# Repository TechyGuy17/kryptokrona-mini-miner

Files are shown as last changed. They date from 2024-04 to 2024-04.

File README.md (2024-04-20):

** THE HARDWARE IS CURRENTLY NOT TESTED **

# Kryptokrona mini miner
A bare minimum miner with a Cortex-A53 Allwinner H616 SoC made with KiCad

<p align="center">
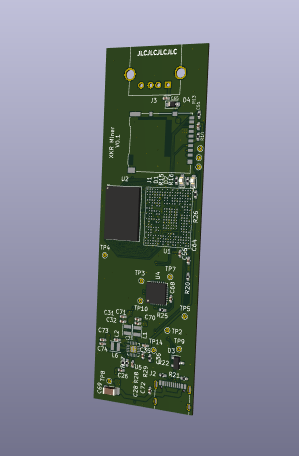
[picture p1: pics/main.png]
     
</p>

## Overview
A simple as possible SBC for mining kryptokrona (XKR), based on [Kononenko-K's h616 devboard](https://github.com/Kononenko-K/Allwinner_H616_Devboard/)

## [Hardware](Hardware)

The board features 64-bit 1.5GHz Quad-Core Cortex-A53 Allwinner H616 SOC, up to 8 Gbit (1 GB) of FBGA-96 16x DDR3 RAM, Micro SD slot, USB HS Host connector and integrated CP2102 USB-UART converter. 4 layers; 3,5/3,5 mil; 0,35/0,15 via, 80u prepreg.
There are [KiCad project](/Hardware), [Gerber files](/Hardware/gerber) and [PDF](/Hardware/output.pdf) avaliable.

## Software
** NOT TESTED SOFTWARE, IT COMPILES BUT MIGHT NOT ACTUALLY WORK ** 
Due to the switch to the more accessable AXP313a, the project is no longer fully compatible with the Orange Pi zero 2- But there is a workaround!

For this guide we will be using armbian, since its lightweight and has support for our processor.

The recommended OS to run this in is Ubuntu 22.04

start by downloading this repo to get the necessary files

```git clone https://github.com/TechyGuy17/kryptokrona-mini-miner```

After that we want to download the "Armbian Builder"

```git clone https://github.com/armbian/build && cd build```

Now we will do a dry run of the builder to let it download all the sources and also fix the file structure

```./compile.sh build BOARD=orangepizero2 BRANCH=current BUILD_DESKTOP=no BUILD_MINIMAL=yes KERNEL_CONFIGURE=no RELEASE=bookworm```

Now we are ready to start doing the patching. If you havent moved around the folders you can use theese commands to do the whole process

```mkdir userpatches/kernel/archive/sunxi-6.6```

```cp ../kryptokrona-mini-miner/Patches/updated-tp-axp313a.patch userpatches/kernel/archive/sunxi-6.6 ```

```cp ../kryptokrona-mini-miner/Patches/updated-tp-axp313a-uboot.patch userpatches/u-boot/u-boot-sunxi```

What this does is move in a few files that make it so we switch out everything regarding the AXP305 to 313a

Now we are ready to build for real!

```./compile.sh build BOARD=orangepizero2 BRANCH=current BUILD_DESKTOP=no BUILD_MINIMAL=yes KERNEL_CONFIGURE=no RELEASE=bookworm```

After this, you should have an image ready to be flashed to a SD card and then ready to be booted! Plug in an wifi/ethernet adapter in the board and a USB-c cable from your computer to the miner and then it should light up! The board will show up as a serial device and can be accessed through software like puTTY or minicom. settings are 115200,8,1 meaning 115200 baud rate, 8 bits and one stop bit.

# Bonus
If you want XKRig (XMRig) preinstalled to your keep on reading!

Run the following command to move the required script to the right folder 
```mv ../kryptokrona-mini-miner/Patches/customize-image.sh userpatches```

When this is in place, rerun the compile 

```./compile.sh build BOARD=orangepizero2 BRANCH=current BUILD_DESKTOP=no BUILD_MINIMAL=yes KERNEL_CONFIGURE=no RELEASE=bookworm```

This will go a lot faster since most the code is cached by now

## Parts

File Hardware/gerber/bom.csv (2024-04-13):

Designator | Footprint | Quantity | Value | LCSC Part #
C1, C2, C58, C61, C62 | 0402 | 5 | 100n
C10, C11, C12, C13, C14, C3, C4, C5, C57, C6, C72, C8, C9 | 0402 | 13 | 1u
C26, C27, C28, C29, C30, C31, C32, C33, C34, C35, C36, C51, C70, C71, C73, C74 | 0402 | 16 | 10u
C40, C41, C42, C43, C44, C45, C46, C47, C48, C49, C50, C52, C53, C56 | 0402 | 14 | 2.2u
C54, C55 | 0402 | 2 | 470n
C59, C60 | 0402 | 2 | 18p
C63 | 0402 | 1 | 220n
C64 | 0402 | 1 | 1n
C65, C68 | 0402 | 2 | 4.7u
C66, C67, C69 | 1206 | 3 | 47u
C7 | 0402 | 1 | 2.2p
D1, D2 | 0603 | 2 | LED
D3 | SOT-23 | 1 | SP0502BAHT
D4 | D_SOD-323_HandSoldering | 1 | D_Schottky
J1 | microSD_HC_Hirose_DM3AT-SF-PEJM5 | 1 | Micro_SD_Card_Det2
J2 | USB_C_Receptacle_Palconn_UTC16-G | 1 | USB_C_Receptacle_USB2.0
J3 | USB_A_Molex_67643_Horizontal | 1 | USB_A
L1, L2, L6 | L_Changjiang_FNR252010S | 3 | 1,5uH
R1, R15, R16, R17, R18, R2 | 0402 | 6 | 2k
R10 | 0402 | 1 | 1R
R11 | 0402 | 1 | 33R
R12, R13, R20, R25, R26 | 0402 | 5 | 10k
R14 | 0402 | 1 | 1k
R19 | 0402 | 1 | 150k
R21, R22 | 0402 | 2 | 5.1k
R27, R28 | 0402 | 2 | NC
R29 | 0402 | 1 | 0R
R3, R5, R6 | 0402 | 3 | 240R
R4 | 0402 | 1 | 100R
TP10, TP11, TP12, TP13, TP14, TP2, TP3, TP4, TP5, TP7, TP8, TP9 | TestPoint_THTPad_D1.0mm_Drill0.5mm | 12 | TestPoint
U1 | H616_TFBGA284 | 1 | H616
U2 | BGA-96_9.0x13.0mm_Layout2x3x16_P0.8mm | 1 | DDR3 FBGA-96
U4 | QFN-28-1EP_5x5mm_P0.5mm_EP3.35x3.35mm | 1 | CP2102N-Axx-xQFN28
U5 | QFN-20-1EP_3x3mm_P0.4mm_EP1.65x1.65mm_ThermalVias | 1 | ~
Y1 | Crystal_SMD_2520-4Pin_2.5x2.0mm | 1 | 25MHz

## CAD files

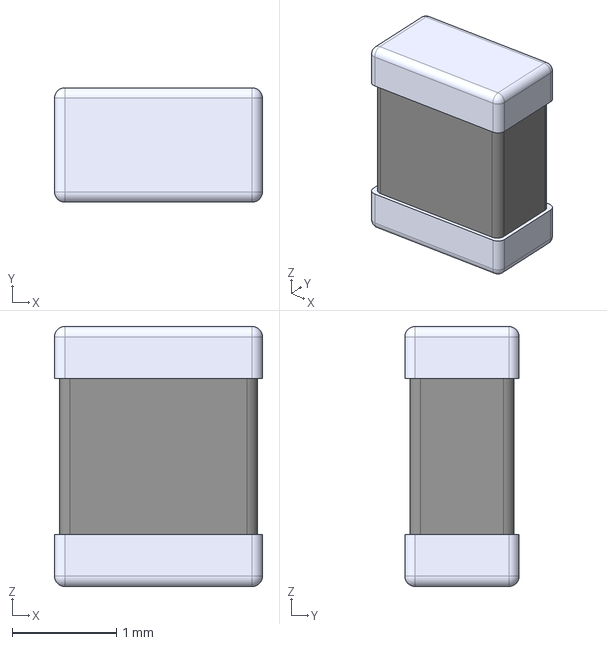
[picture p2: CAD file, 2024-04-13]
Hardware/Inductor_2520.step
2.00 x 1.10 x 2.50 mm

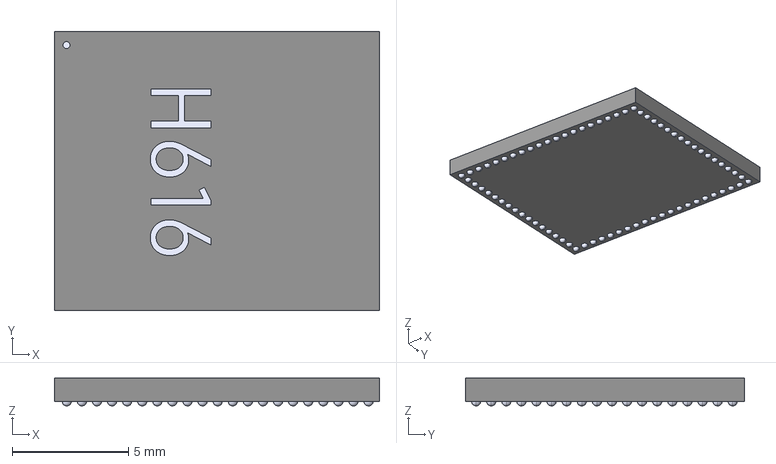
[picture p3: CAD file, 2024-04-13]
Hardware/SoC_H616.step
14.0 x 12.0 x 1.20 mm

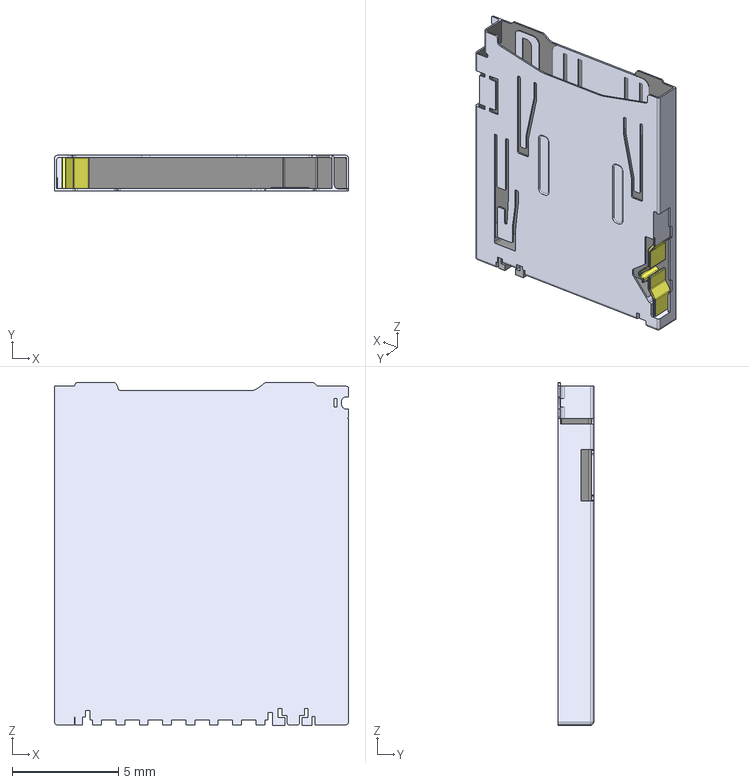
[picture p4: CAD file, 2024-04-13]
Hardware/MicroSD_DM3AT.step
13.8 x 1.68 x 16.2 mm

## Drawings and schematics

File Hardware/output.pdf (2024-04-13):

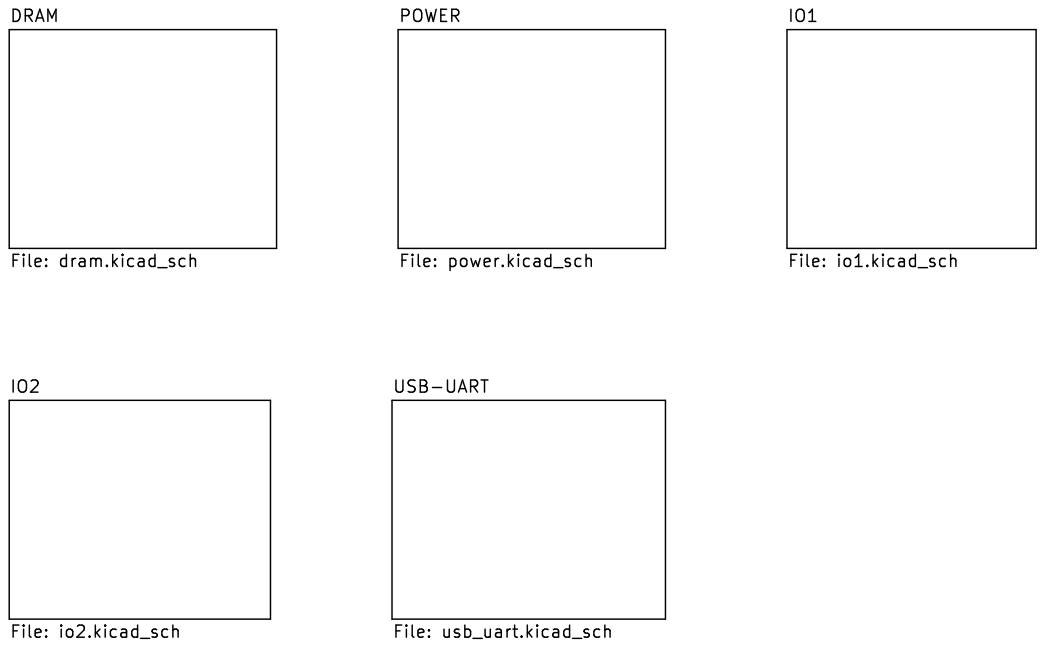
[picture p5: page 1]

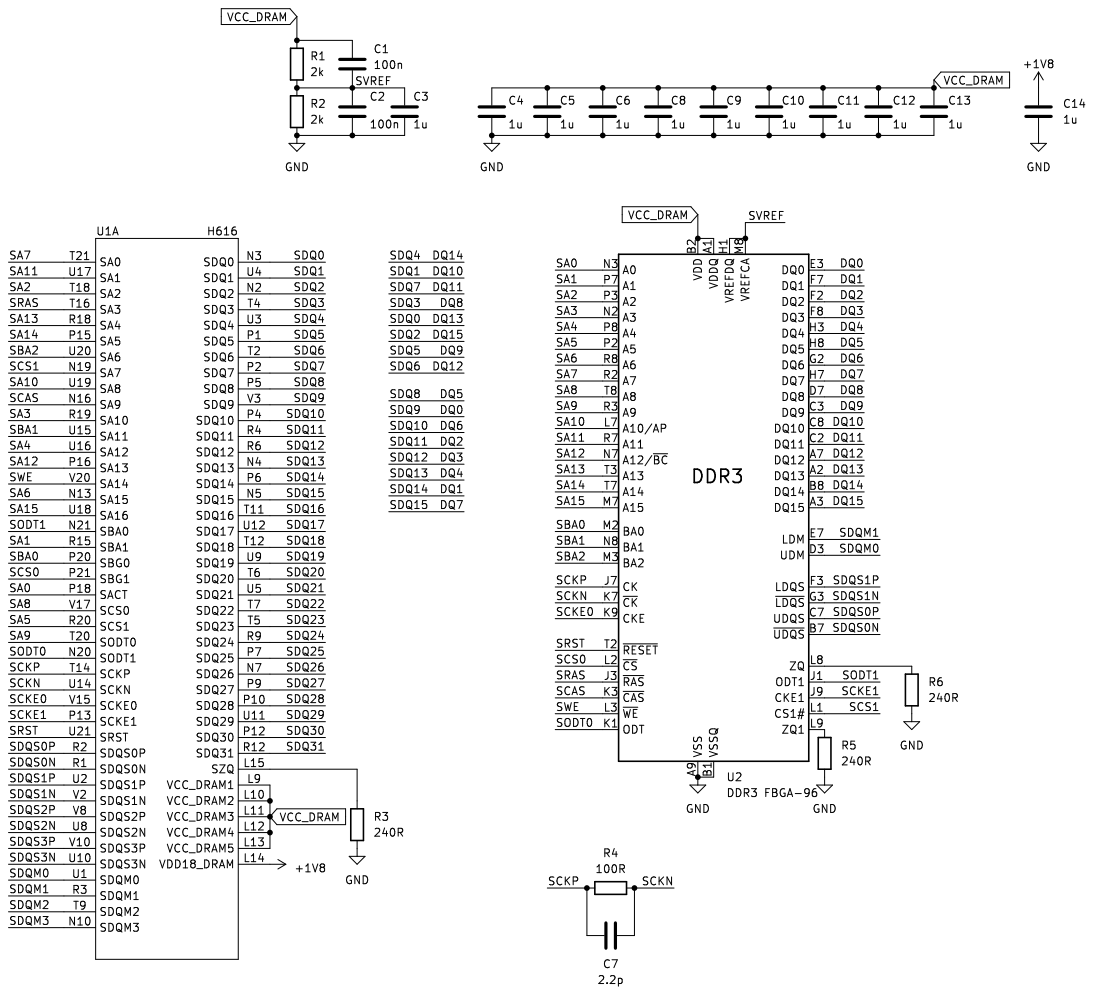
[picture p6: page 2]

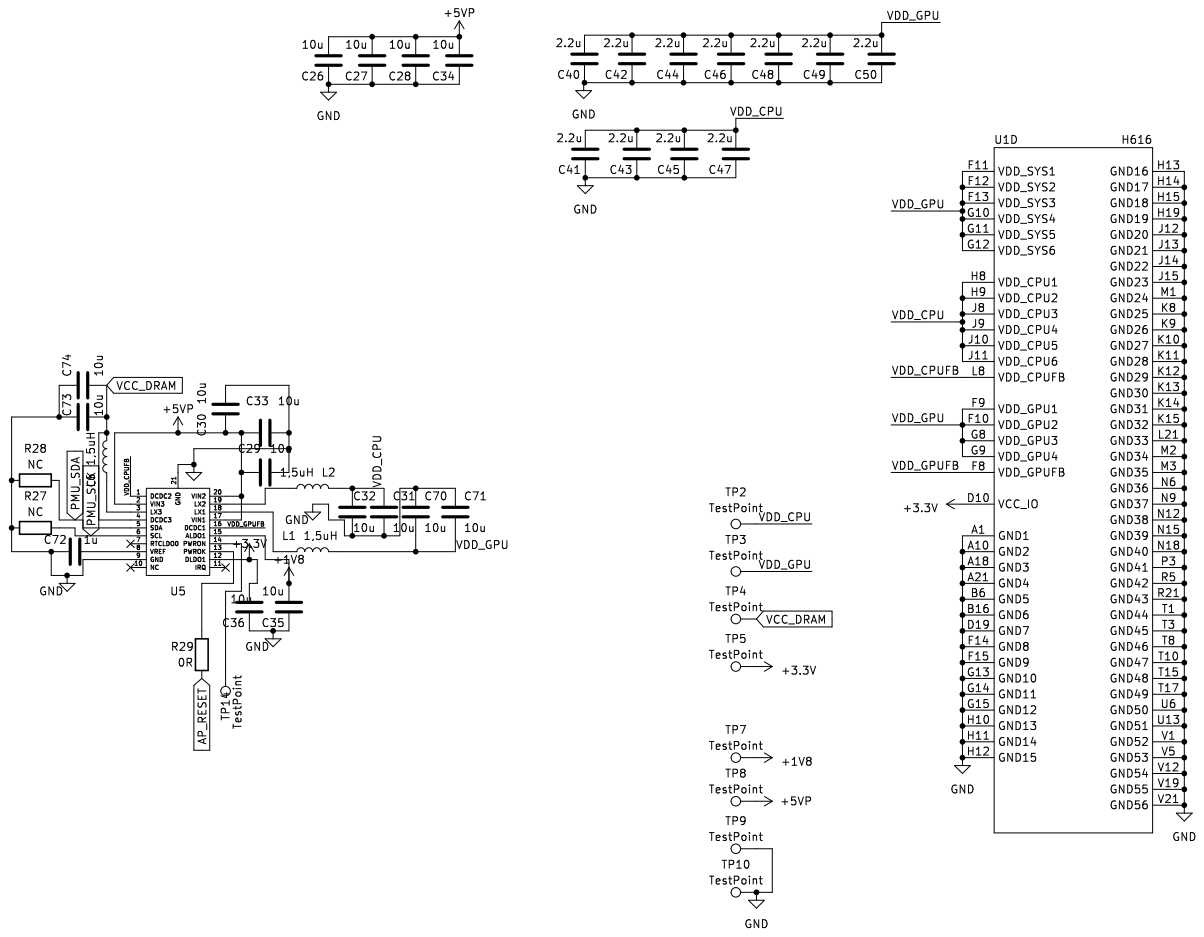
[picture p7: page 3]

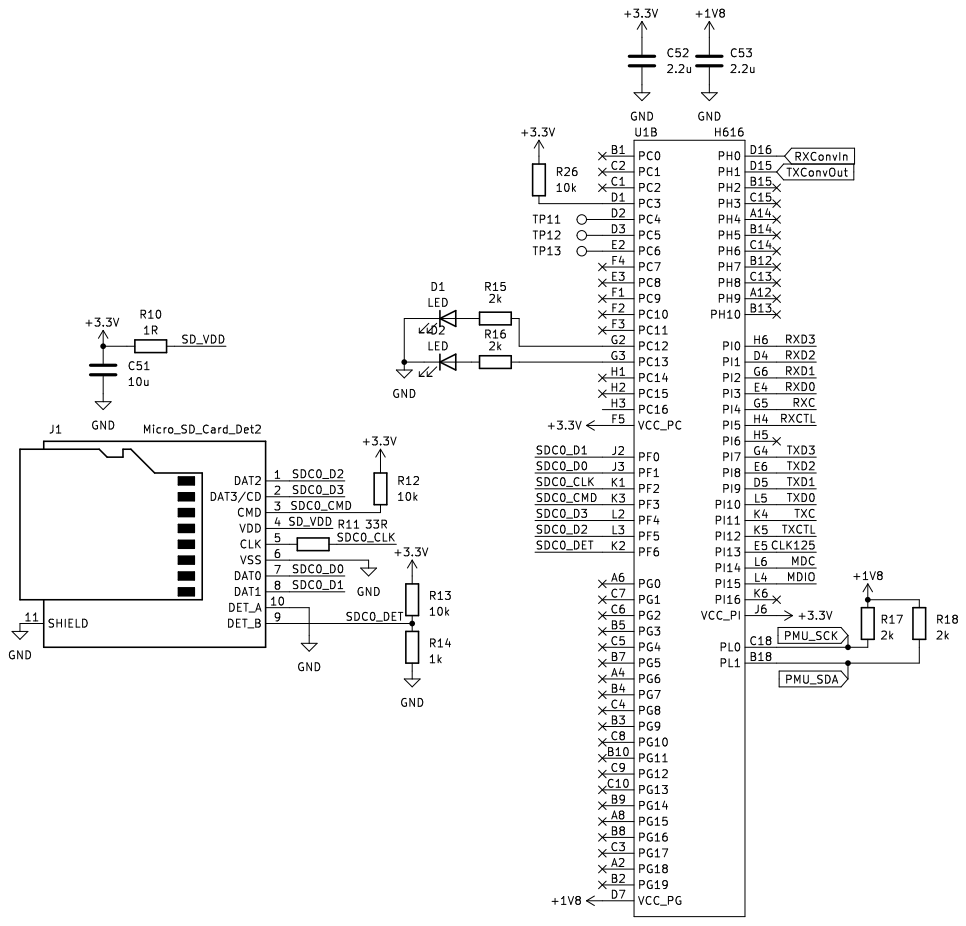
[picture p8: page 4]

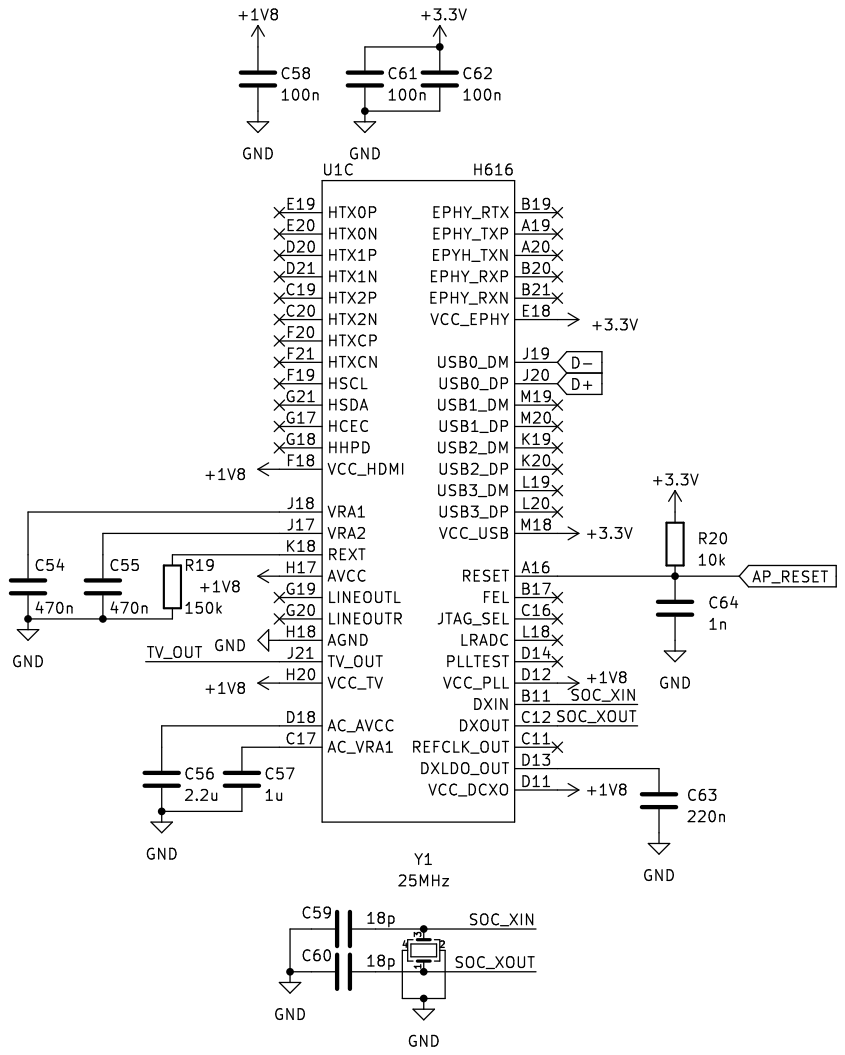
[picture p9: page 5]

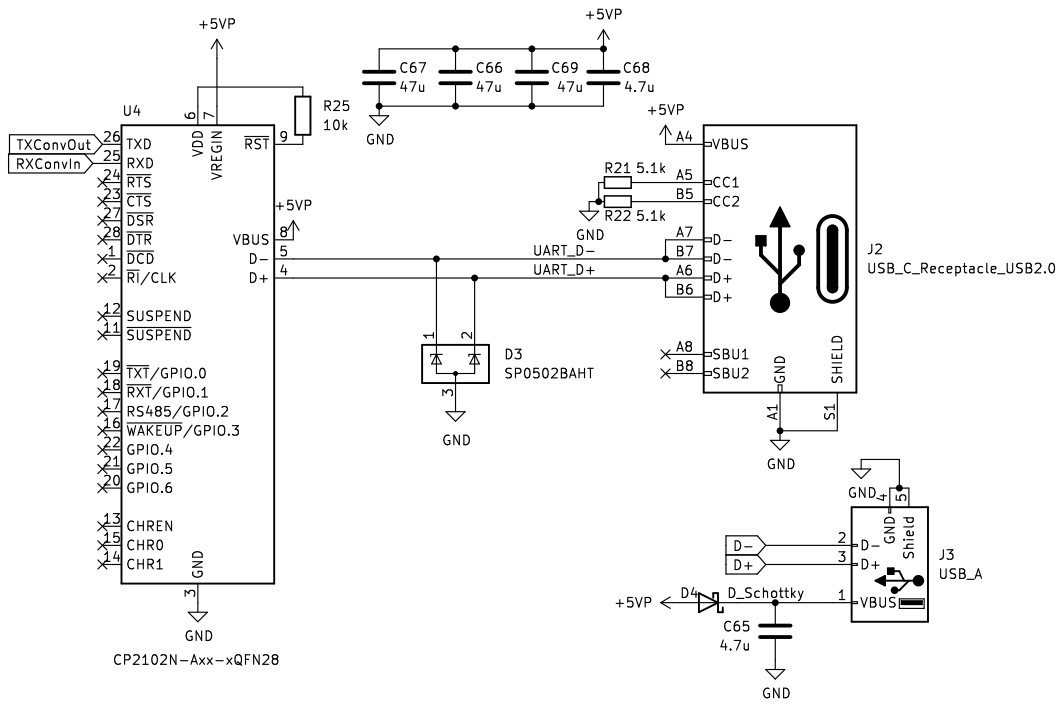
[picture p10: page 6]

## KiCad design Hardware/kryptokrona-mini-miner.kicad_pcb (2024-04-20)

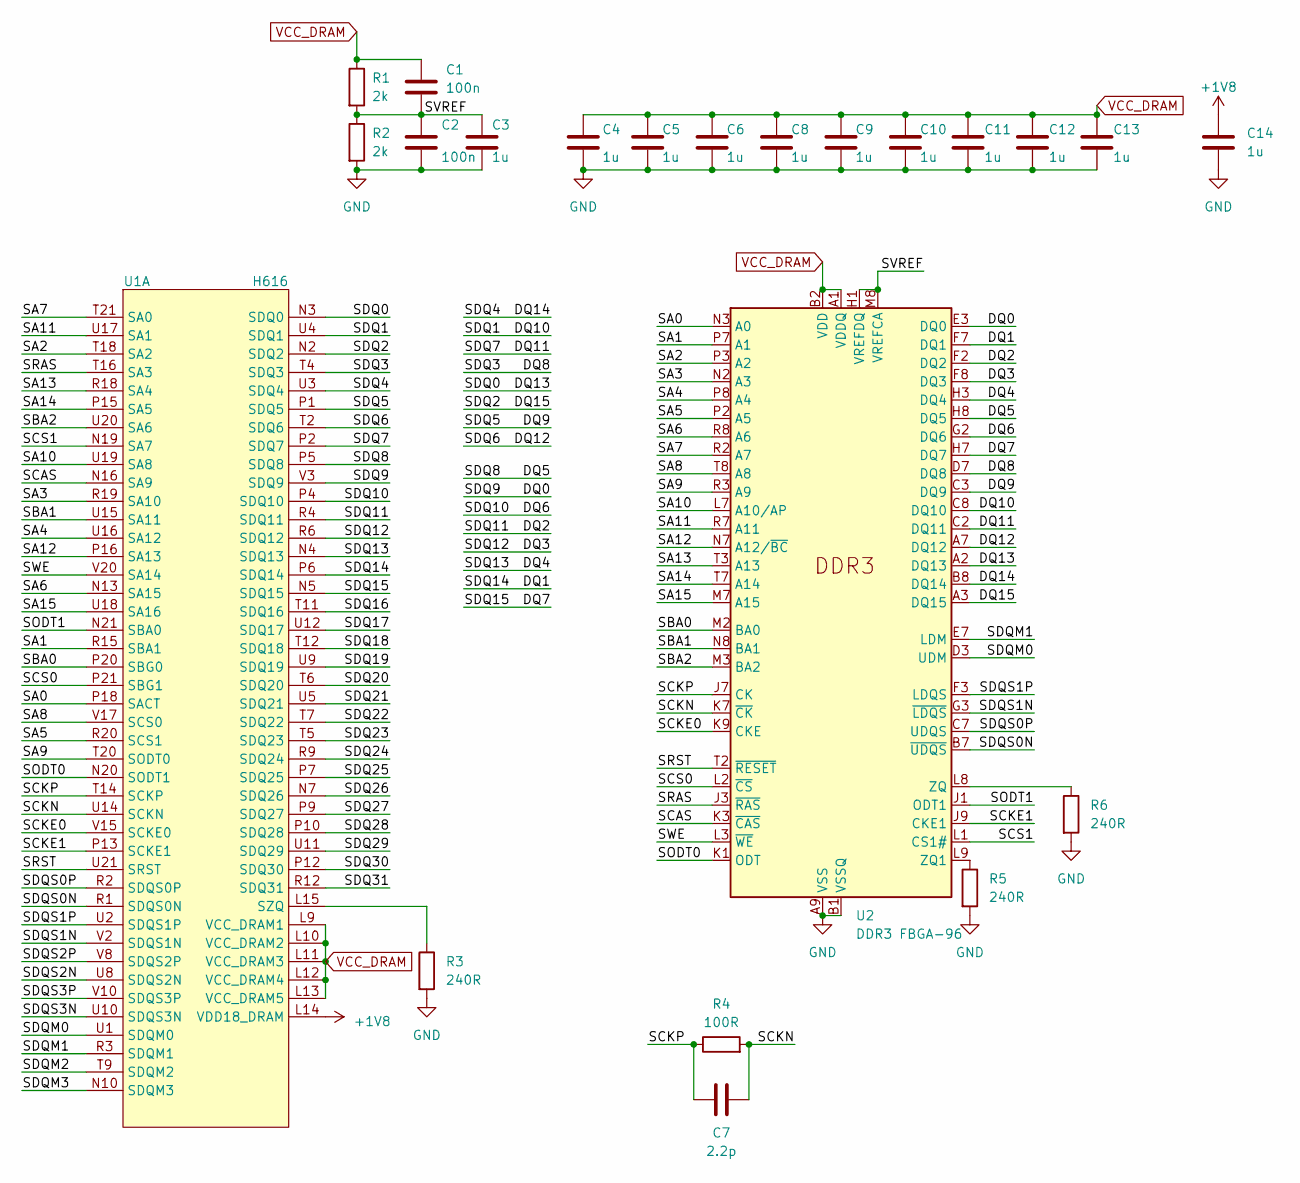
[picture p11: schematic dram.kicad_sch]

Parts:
C1, C2: 100n; C_0402_1005Metric_Pad0.74x0.62mm_HandSolder
C3, C4, C5, C6, C8, C9, C10, C11, C12, C13, C14: 1u; C_0402_1005Metric_Pad0.74x0.62mm_HandSolder
C7: 2.2p; C_0402_1005Metric_Pad0.74x0.62mm_HandSolder
R1, R2: 2k; R_0402_1005Metric_Pad0.72x0.64mm_HandSolder
R3, R5, R6: 240R; R_0402_1005Metric_Pad0.72x0.64mm_HandSolder
R4: 100R; R_0402_1005Metric_Pad0.72x0.64mm_HandSolder
U1: H616; H616_TFBGA284
U2: DDR3 FBGA-96; BGA-96_9.0x13.0mm_Layout2x3x16_P0.8mm

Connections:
+1V8: C14.1, U1.L14 (VDD18_DRAM); also elsewhere on the board
/DRAM/DQ0: U1.V3 (SDQ9), U2.E3 (DQ0)
/DRAM/DQ1: U1.P6 (SDQ14), U2.F7 (DQ1)
/DRAM/DQ2: U1.R4 (SDQ11), U2.F2 (DQ2)
/DRAM/DQ3: U1.R6 (SDQ12), U2.F8 (DQ3)
/DRAM/DQ4: U1.N4 (SDQ13), U2.H3 (DQ4)
/DRAM/DQ5: U1.P5 (SDQ8), U2.H8 (DQ5)
/DRAM/DQ6: U1.P4 (SDQ10), U2.G2 (DQ6)
/DRAM/DQ7: U1.N5 (SDQ15), U2.H7 (DQ7)
/DRAM/DQ8: U1.T4 (SDQ3), U2.D7 (DQ8)
/DRAM/DQ9: U1.P1 (SDQ5), U2.C3 (DQ9)
/DRAM/DQ10: U1.U4 (SDQ1), U2.C8 (DQ10)
/DRAM/DQ11: U1.P2 (SDQ7), U2.C2 (DQ11)
/DRAM/DQ12: U1.T2 (SDQ6), U2.A7 (DQ12)
/DRAM/DQ13: U1.N3 (SDQ0), U2.A2 (DQ13)
/DRAM/DQ14: U1.U3 (SDQ4), U2.B8 (DQ14)
/DRAM/DQ15: U1.N2 (SDQ2), U2.A3 (DQ15)
/DRAM/SA0: U1.P18 (SACT), U2.N3 (A0)
/DRAM/SA1: U1.R15 (SBA1), U2.P7 (A1)
/DRAM/SA2: U1.T18 (SA2), U2.P3 (A2)
/DRAM/SA3: U1.R19 (SA10), U2.N2 (A3)
/DRAM/SA4: U1.U16 (SA12), U2.P8 (A4)
/DRAM/SA5: U1.R20 (SCS1), U2.P2 (A5)
/DRAM/SA6: U1.N13 (SA15), U2.R8 (A6)
/DRAM/SA7: U1.T21 (SA0), U2.R2 (A7)
/DRAM/SA8: U1.V17 (SCS0), U2.T8 (A8)
/DRAM/SA9: U1.T20 (SODT0), U2.R3 (A9)
/DRAM/SA10: U1.U19 (SA8), U2.L7 (A10/AP)
/DRAM/SA11: U1.U17 (SA1), U2.R7 (A11)
/DRAM/SA12: U1.P16 (SA13), U2.N7 (A12/~BC)
/DRAM/SA13: U1.R18 (SA4), U2.T3 (A13)
/DRAM/SA14: U1.P15 (SA5), U2.T7 (A14)
/DRAM/SA15: U1.U18 (SA16), U2.M7 (A15)
/DRAM/SBA0: U1.P20 (SBG0), U2.M2 (BA0)
/DRAM/SBA1: U1.U15 (SA11), U2.N8 (BA1)
/DRAM/SBA2: U1.U20 (SA6), U2.M3 (BA2)
/DRAM/SCAS: U1.N16 (SA9), U2.K3 (~CAS)
/DRAM/SCKE0: U1.V15 (SCKE0), U2.K9 (CKE)
/DRAM/SCKE1: U1.P13 (SCKE1), U2.J9 (CKE1)
/DRAM/SCKN: C7.2, R4.2, U1.U14 (SCKN), U2.K7 (~CK)
/DRAM/SCKP: C7.1, R4.1, U1.T14 (SCKP), U2.J7 (CK)
/DRAM/SCS0: U1.P21 (SBG1), U2.L2 (~CS)
/DRAM/SCS1: U1.N19 (SA7), U2.L1 (CS1#)
/DRAM/SDQ16: U1.T11 (SDQ16)
/DRAM/SDQ17: U1.U12 (SDQ17)
/DRAM/SDQ18: U1.T12 (SDQ18)
/DRAM/SDQ19: U1.U9 (SDQ19)
/DRAM/SDQ20: U1.T6 (SDQ20)
/DRAM/SDQ21: U1.U5 (SDQ21)
/DRAM/SDQ22: U1.T7 (SDQ22)
/DRAM/SDQ23: U1.T5 (SDQ23)
/DRAM/SDQ24: U1.R9 (SDQ24)
/DRAM/SDQ25: U1.P7 (SDQ25)
/DRAM/SDQ26: U1.N7 (SDQ26)
/DRAM/SDQ27: U1.P9 (SDQ27)
/DRAM/SDQ28: U1.P10 (SDQ28)
/DRAM/SDQ29: U1.U11 (SDQ29)
/DRAM/SDQ30: U1.P12 (SDQ30)
/DRAM/SDQ31: U1.R12 (SDQ31)
/DRAM/SDQM0: U1.U1 (SDQM0), U2.D3 (UDM)
/DRAM/SDQM1: U1.R3 (SDQM1), U2.E7 (LDM)
/DRAM/SDQM2: U1.T9 (SDQM2)
/DRAM/SDQM3: U1.N10 (SDQM3)
/DRAM/SDQS0N: U1.R1 (SDQS0N), U2.B7 (~UDQS)
/DRAM/SDQS0P: U1.R2 (SDQS0P), U2.C7 (UDQS)
/DRAM/SDQS1N: U1.V2 (SDQS1N), U2.G3 (~LDQS)
/DRAM/SDQS1P: U1.U2 (SDQS1P), U2.F3 (LDQS)
/DRAM/SDQS2N: U1.U8 (SDQS2N)
/DRAM/SDQS2P: U1.V8 (SDQS2P)
/DRAM/SDQS3N: U1.U10 (SDQS3N)
/DRAM/SDQS3P: U1.V10 (SDQS3P)
/DRAM/SODT0: U1.N20 (SODT1), U2.K1 (ODT)
/DRAM/SODT1: U1.N21 (SBA0), U2.J1 (ODT1)
/DRAM/SRAS: U1.T16 (SA3), U2.J3 (~RAS)
/DRAM/SRST: U1.U21 (SRST), U2.T2 (~RESET)
/DRAM/SVREF: C1.2, C2.1, C3.1, R1.2, R2.1, U2.H1 (VREFDQ), U2.M8 (VREFCA)
/DRAM/SWE: U1.V20 (SA14), U2.L3 (~WE)
GND: C2.2, C3.2, C4.2, C5.2, C6.2, C8.2, C9.2, C10.2, C11.2, C12.2, C13.2, C14.2, R2.2, R3.2, R5.2, R6.2, U2.A9 (VSS), U2.B1 (VSSQ), U2.B3 (VSS), U2.B9 (VSSQ), U2.D1 (VSSQ), U2.D8 (VSSQ), U2.E1 (VSS), U2.E2 (VSSQ), U2.E8 (VSSQ), U2.F9 (VSSQ), U2.G1 (VSSQ), U2.G8 (VSS), U2.G9 (VSSQ), U2.J2 (VSS), U2.J8 (VSS), U2.M1 (VSS), U2.M9 (VSS), U2.P1 (VSS), U2.P9 (VSS), U2.T1 (VSS), U2.T9 (VSS); also elsewhere on the board
unnamed: R3.1, U1.L15 (SZQ)
unnamed: R5.1, U2.L9 (ZQ1)
unnamed: R6.1, U2.L8 (ZQ)
VCC_DRAM: C1.1, C4.1, C5.1, C6.1, C8.1, C9.1, C10.1, C11.1, C12.1, C13.1, R1.1, U1.L9 (VCC_DRAM1), U1.L10 (VCC_DRAM2), U1.L11 (VCC_DRAM3), U1.L12 (VCC_DRAM4), U1.L13 (VCC_DRAM5), U2.A1 (VDDQ), U2.A8 (VDDQ), U2.B2 (VDD), U2.C1 (VDDQ), U2.C9 (VDDQ), U2.D2 (VDDQ), U2.D9 (VDD), U2.E9 (VDDQ), U2.F1 (VDDQ), U2.G7 (VDD), U2.H2 (VDDQ), U2.H9 (VDDQ), U2.K2 (VDD), U2.K8 (VDD), U2.N1 (VDD), U2.N9 (VDD), U2.R1 (VDD), U2.R9 (VDD); also elsewhere on the board

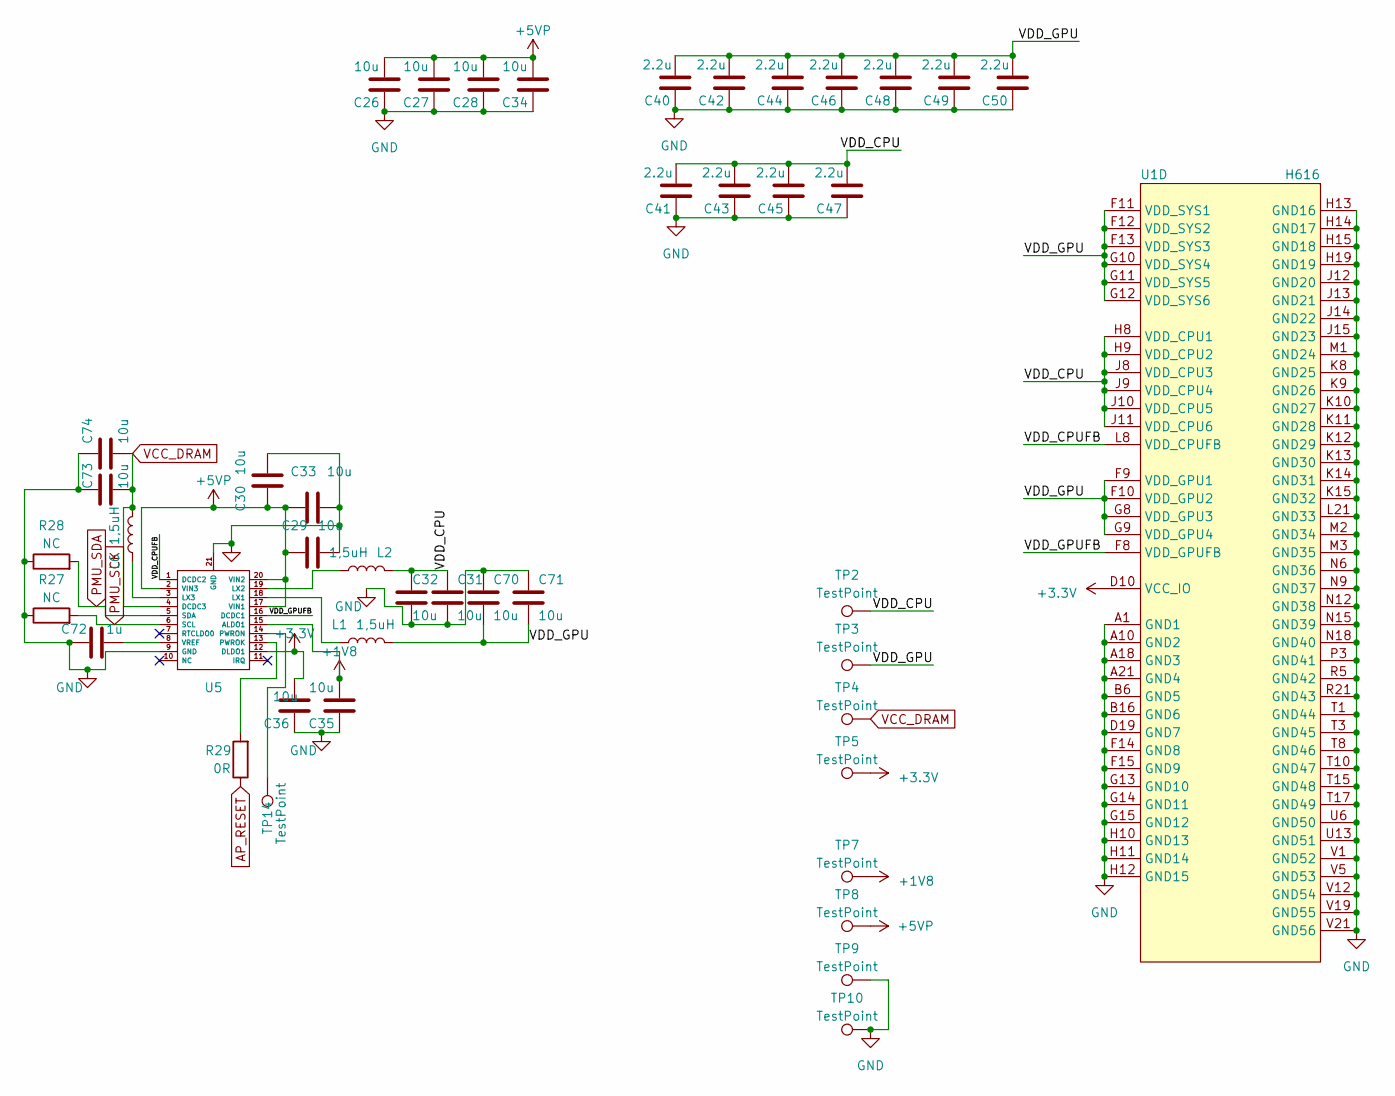
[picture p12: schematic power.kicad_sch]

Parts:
C26, C27, C28, C29, C30, C31, C32, C33, C34, C35, C36, C70, C71, C73, C74: 10u; C_0402_1005Metric_Pad0.74x0.62mm_HandSolder
C40, C41, C42, C43, C44, C45, C46, C47, C48, C49, C50: 2.2u; C_0402_1005Metric_Pad0.74x0.62mm_HandSolder
C72: 1u; C_0402_1005Metric_Pad0.74x0.62mm_HandSolder
L1, L2, L6: 1,5uH; L_Changjiang_FNR252010S
R27, R28: NC; R_0402_1005Metric_Pad0.72x0.64mm_HandSolder
R29: 0R; R_0402_1005Metric_Pad0.72x0.64mm_HandSolder
TP2, TP3, TP4, TP5, TP7, TP8, TP9, TP10, TP14: TestPoint; TestPoint_THTPad_D1.0mm_Drill0.5mm
U1: H616; H616_TFBGA284
U5: QFN-20-1EP_3x3mm_P0.4mm_EP1.65x1.65mm_ThermalVias

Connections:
+1V8: C35.2, TP7.1, U5.15 (ALDO1); also elsewhere on the board
+3.3V: C36.2, TP5.1, U1.D10 (VCC_IO), U5.12 (DLDO1); also elsewhere on the board
+5VP: C26.2, C27.2, C28.2, C29.1, C30.1, C33.1, C34.2, TP8.1, U5.2 (VIN3), U5.17 (VIN1), U5.20 (VIN2); also elsewhere on the board
/POWER/VDD_CPU: C31.1, C32.1, C41.2, C43.2, C45.2, C47.2, L2.1, TP2.1, U1.H8 (VDD_CPU1), U1.H9 (VDD_CPU2), U1.J8 (VDD_CPU3), U1.J9 (VDD_CPU4), U1.J10 (VDD_CPU5), U1.J11 (VDD_CPU6)
/POWER/VDD_CPUFB: U1.L8 (VDD_CPUFB), U5.1 (DCDC2)
/POWER/VDD_GPU: C40.2, C42.2, C44.2, C46.2, C48.2, C49.2, C50.2, C70.2, C71.2, L1.2, TP3.1, U1.F9 (VDD_GPU1), U1.F10 (VDD_GPU2), U1.F11 (VDD_SYS1), U1.F12 (VDD_SYS2), U1.F13 (VDD_SYS3), U1.G8 (VDD_GPU3), U1.G9 (VDD_GPU4), U1.G10 (VDD_SYS4), U1.G11 (VDD_SYS5), U1.G12 (VDD_SYS6)
/POWER/VDD_GPUFB: U1.F8 (VDD_GPUFB), U5.16 (DCDC1)
AP_RESET: R29.1; also elsewhere on the board
GND: C26.1, C27.1, C28.1, C29.2, C30.2, C31.2, C32.2, C33.2, C34.1, C35.1, C36.1, C40.1, C41.1, C42.1, C43.1, C44.1, C45.1, C46.1, C47.1, C48.1, C49.1, C50.1, C70.1, C71.1, C72.1, C73.1, C74.1, R27.1, R28.1, TP9.1, TP10.1, U1.A1 (GND1), U1.A10 (GND2), U1.A18 (GND3), U1.A21 (GND4), U1.B6 (GND5), U1.B16 (GND6), U1.D19 (GND7), U1.F14 (GND8), U1.F15 (GND9), U1.G13 (GND10), U1.G14 (GND11), U1.G15 (GND12), U1.H10 (GND13), U1.H11 (GND14), U1.H12 (GND15), U1.H13 (GND16), U1.H14 (GND17), U1.H15 (GND18), U1.H19 (GND19), U1.J12 (GND20), U1.J13 (GND21), U1.J14 (GND22), U1.J15 (GND23), U1.K8 (GND25), U1.K9 (GND26), U1.K10 (GND27), U1.K11 (GND28), U1.K12 (GND29), U1.K13 (GND30), U1.K14 (GND31), U1.K15 (GND32), U1.L21 (GND33), U1.M1 (GND24), U1.M2 (GND34), U1.M3 (GND35), U1.N6 (GND36), U1.N9 (GND37), U1.N12 (GND38), U1.N15 (GND39), U1.N18 (GND40), U1.P3 (GND41), U1.R5 (GND42), U1.R21 (GND43), U1.T1 (GND44), U1.T3 (GND45), U1.T8 (GND46), U1.T10 (GND47), U1.T15 (GND48), U1.T17 (GND49), U1.U6 (GND50), U1.U13 (GND51), U1.V1 (GND52), U1.V5 (GND53), U1.V12 (GND54), U1.V19 (GND55), U1.V21 (GND56), U5.9 (GND), U5.21 (GND); also elsewhere on the board
unnamed: L1.1, U5.18 (LX1)
unnamed: L2.2, U5.19 (LX2)
unnamed: L6.1, U5.3 (LX3)
unnamed: R29.2, U5.13 (PWROK)
unnamed: TP14.1, U5.14 (PWRON)
unnamed: C72.2, U5.8 (VREF)
PMU_SCK: R27.2, U5.6 (SCL); also elsewhere on the board
PMU_SDA: R28.2, U5.5 (SDA); also elsewhere on the board
VCC_DRAM: C73.2, C74.2, L6.2, TP4.1, U5.4 (DCDC3); also elsewhere on the board

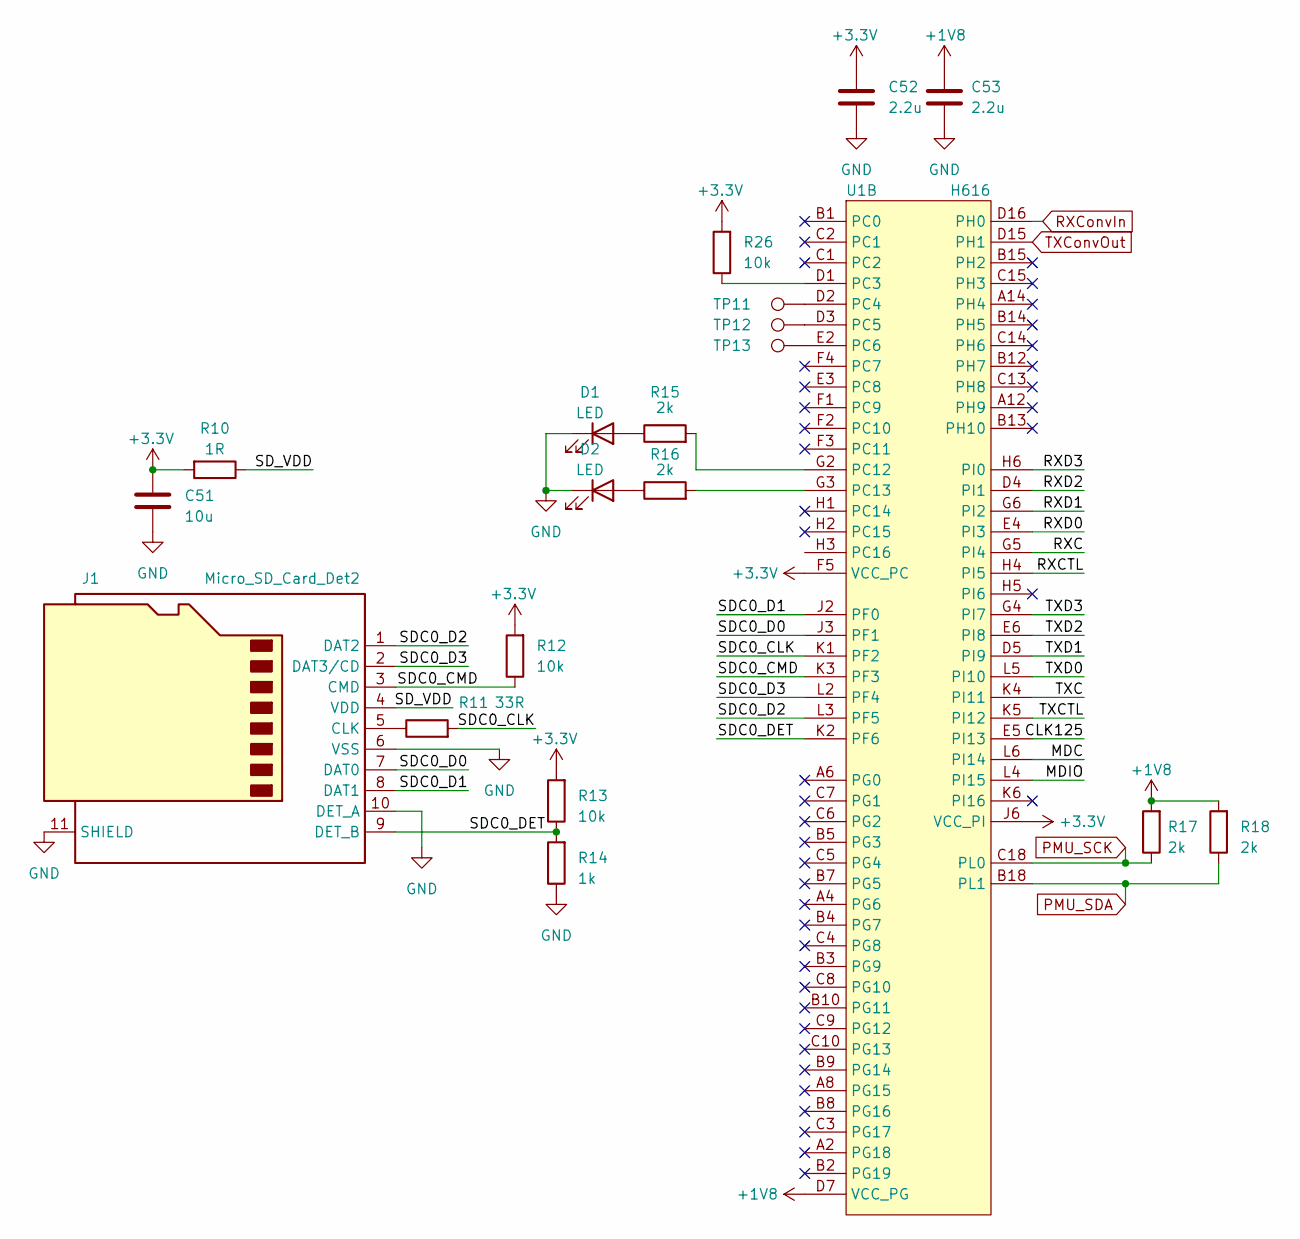
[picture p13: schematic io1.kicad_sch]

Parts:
C51: 10u; C_0402_1005Metric_Pad0.74x0.62mm_HandSolder
C52, C53: 2.2u; C_0402_1005Metric_Pad0.74x0.62mm_HandSolder
D1, D2: LED; LED_0603_1608Metric_Pad1.05x0.95mm_HandSolder
J1: Micro_SD_Card_Det2; microSD_HC_Hirose_DM3AT-SF-PEJM5
R10: 1R; R_0402_1005Metric_Pad0.72x0.64mm_HandSolder
R11: 33R; R_0402_1005Metric_Pad0.72x0.64mm_HandSolder
R12, R13, R26: 10k; R_0402_1005Metric_Pad0.72x0.64mm_HandSolder
R14: 1k; R_0402_1005Metric_Pad0.72x0.64mm_HandSolder
R15, R16, R17, R18: 2k; R_0402_1005Metric_Pad0.72x0.64mm_HandSolder
TP11, TP12, TP13: TestPoint; TestPoint_THTPad_D1.0mm_Drill0.5mm
U1: H616; H616_TFBGA284

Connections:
+1V8: C53.1, R17.2, R18.2, U1.D7 (VCC_PG); also elsewhere on the board
+3.3V: C51.1, C52.1, R10.2, R12.2, R13.2, R26.2, U1.F5 (VCC_PC), U1.J6 (VCC_PI); also elsewhere on the board
/IO1/CLK125: U1.E5 (PI13)
/IO1/MDC: U1.L6 (PI14)
/IO1/MDIO: U1.L4 (PI15)
/IO1/RXC: U1.G5 (PI4)
/IO1/RXCTL: U1.H4 (PI5)
/IO1/RXD0: U1.E4 (PI3)
/IO1/RXD1: U1.G6 (PI2)
/IO1/RXD2: U1.D4 (PI1)
/IO1/RXD3: U1.H6 (PI0)
/IO1/SDC0_CLK: R11.2, U1.K1 (PF2)
/IO1/SDC0_CMD: J1.3 (CMD), R12.1, U1.K3 (PF3)
/IO1/SDC0_D0: J1.7 (DAT0), U1.J3 (PF1)
/IO1/SDC0_D1: J1.8 (DAT1), U1.J2 (PF0)
/IO1/SDC0_D2: J1.1 (DAT2), U1.L3 (PF5)
/IO1/SDC0_D3: J1.2 (DAT3/CD), U1.L2 (PF4)
/IO1/SDC0_DET: J1.9 (DET_B), R13.1, R14.2, U1.K2 (PF6)
/IO1/SD_VDD: J1.4 (VDD), R10.1
/IO1/TXC: U1.K4 (PI11)
/IO1/TXCTL: U1.K5 (PI12)
/IO1/TXD0: U1.L5 (PI10)
/IO1/TXD1: U1.D5 (PI9)
/IO1/TXD2: U1.E6 (PI8)
/IO1/TXD3: U1.G4 (PI7)
GND: C51.2, C52.2, C53.2, D1.1 (K), D2.1 (K), J1.6 (VSS), J1.10 (DET_A), J1.11 (SHIELD), R14.1; also elsewhere on the board
unnamed: D1.2 (A), R15.1
unnamed: D2.2 (A), R16.1
unnamed: J1.5 (CLK), R11.1
unnamed: R26.1, U1.D1 (PC3)
unnamed: TP11.1, U1.D2 (PC4)
unnamed: TP12.1, U1.D3 (PC5)
unnamed: TP13.1, U1.E2 (PC6)
unnamed: R15.2, U1.G2 (PC12)
unnamed: R16.2, U1.G3 (PC13)
PMU_SCK: R17.1, U1.C18 (PL0); also elsewhere on the board
PMU_SDA: R18.1, U1.B18 (PL1); also elsewhere on the board
RXConvIn: U1.D16 (PH0); also elsewhere on the board
TXConvOut: U1.D15 (PH1); also elsewhere on the board

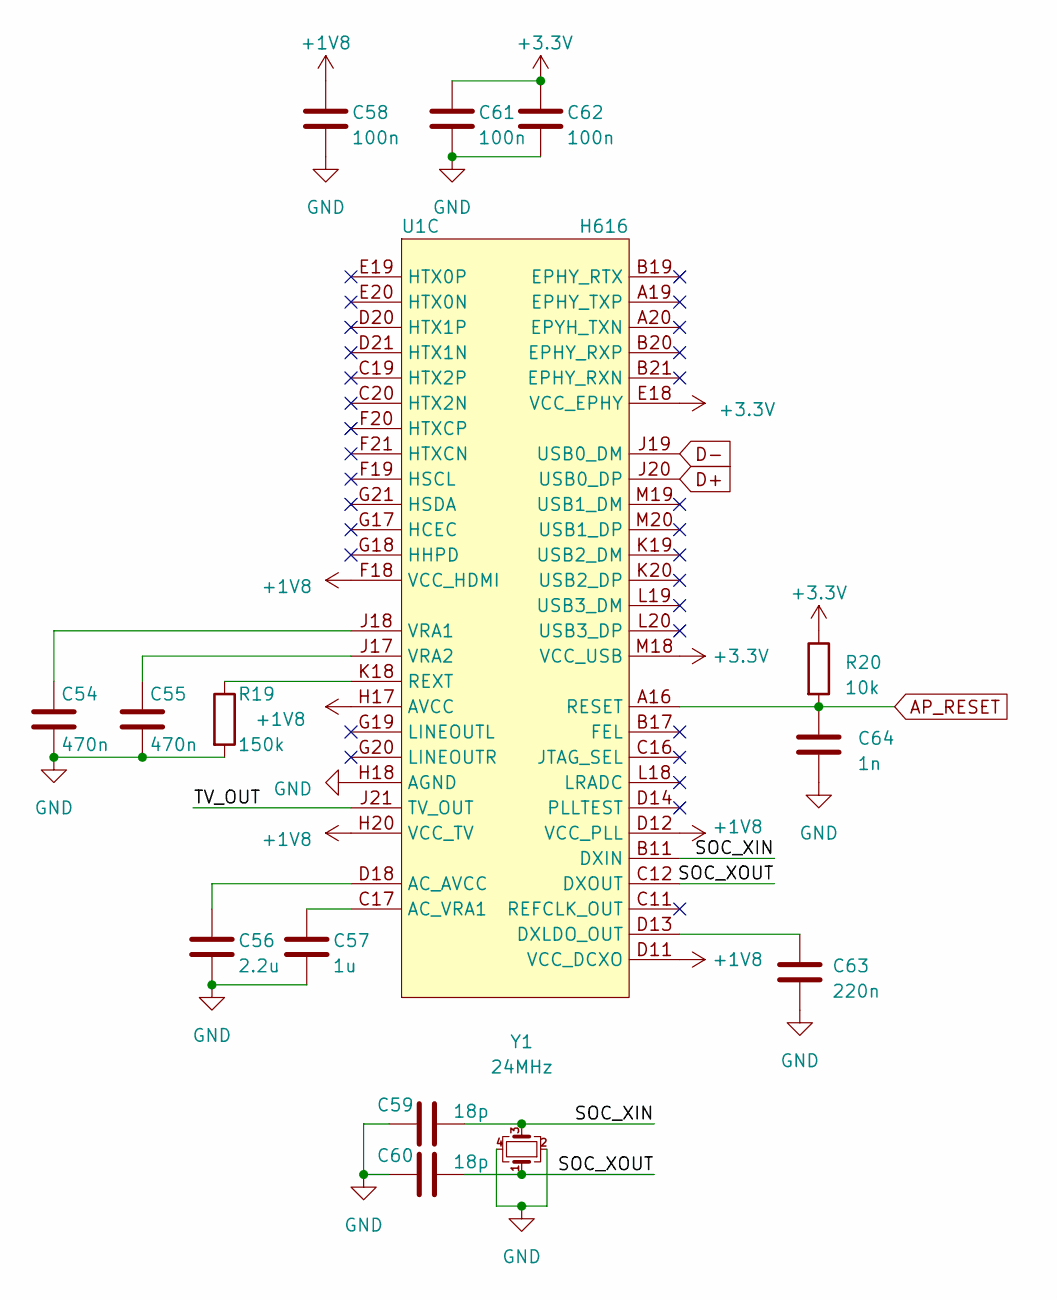
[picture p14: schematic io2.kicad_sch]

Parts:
C54, C55: 470n; C_0402_1005Metric_Pad0.74x0.62mm_HandSolder
C56: 2.2u; C_0402_1005Metric_Pad0.74x0.62mm_HandSolder
C57: 1u; C_0402_1005Metric_Pad0.74x0.62mm_HandSolder
C58, C61, C62: 100n; C_0402_1005Metric_Pad0.74x0.62mm_HandSolder
C59, C60: 18p; C_0402_1005Metric_Pad0.74x0.62mm_HandSolder
C63: 220n; C_0402_1005Metric_Pad0.74x0.62mm_HandSolder
C64: 1n; C_0402_1005Metric_Pad0.74x0.62mm_HandSolder
R19: 150k; R_0402_1005Metric_Pad0.72x0.64mm_HandSolder
R20: 10k; R_0402_1005Metric_Pad0.72x0.64mm_HandSolder
U1: H616; H616_TFBGA284
Y1: 24MHz; Crystal_SMD_2520-4Pin_2.5x2.0mm

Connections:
+1V8: C58.1, U1.D11 (VCC_DCXO), U1.D12 (VCC_PLL), U1.F18 (VCC_HDMI), U1.H17 (AVCC), U1.H20 (VCC_TV); also elsewhere on the board
+3.3V: C61.1, C62.1, R20.1, U1.E18 (VCC_EPHY), U1.M18 (VCC_USB); also elsewhere on the board
/IO2/SOC_XIN: C59.2, U1.B11 (DXIN), Y1.3
/IO2/SOC_XOUT: C60.2, U1.C12 (DXOUT), Y1.1
/IO2/TV_OUT: U1.J21 (TV_OUT)
AP_RESET: C64.1, R20.2, U1.A16 (RESET); also elsewhere on the board
D+: U1.J20 (USB0_DP); also elsewhere on the board
D-: U1.J19 (USB0_DM); also elsewhere on the board
GND: C54.2, C55.2, C56.2, C57.2, C58.2, C59.1, C60.1, C61.2, C62.2, C63.2, C64.2, R19.2, U1.H18 (AGND), Y1.2, Y1.4; also elsewhere on the board
unnamed: C56.1, U1.D18 (AC_AVCC)
unnamed: C57.1, U1.C17 (AC_VRA1)
unnamed: C63.1, U1.D13 (DXLDO_OUT)
unnamed: R19.1, U1.K18 (REXT)
unnamed: C54.1, U1.J18 (VRA1)
unnamed: C55.1, U1.J17 (VRA2)

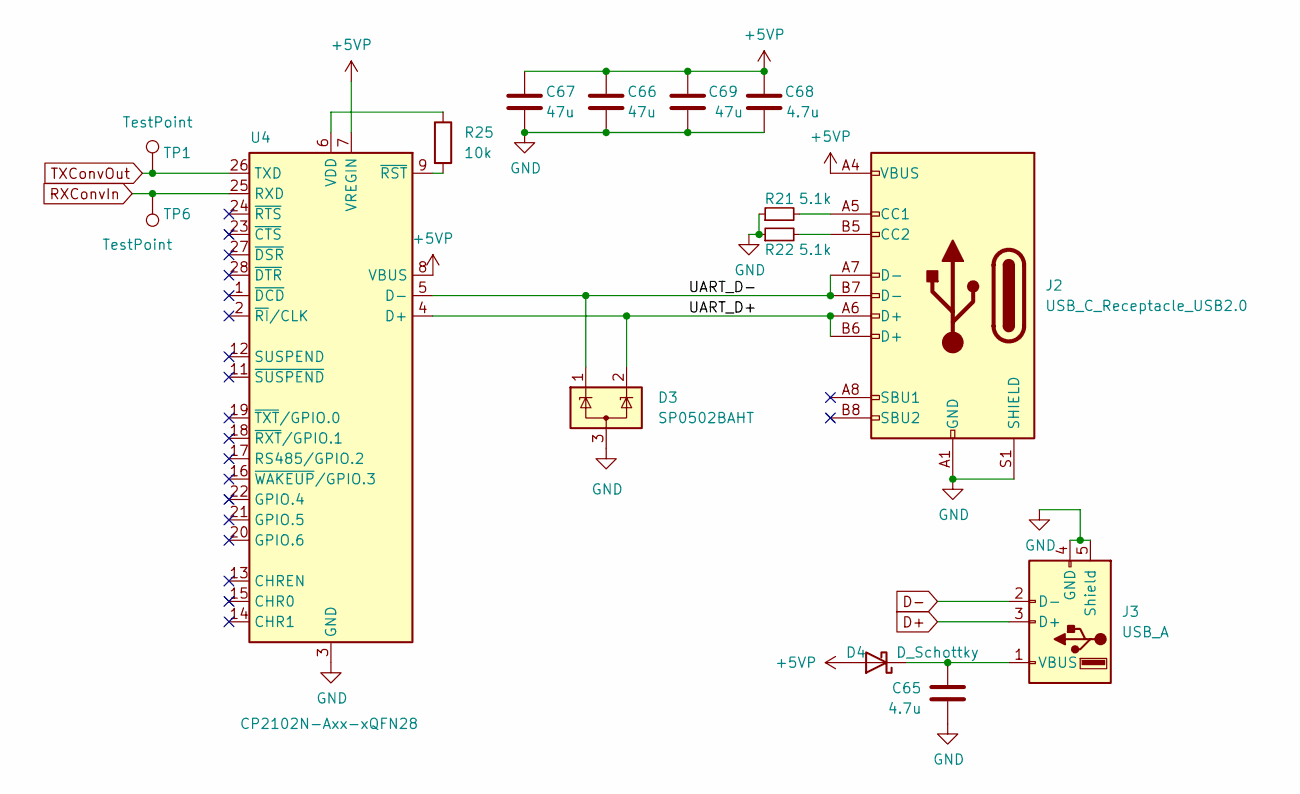
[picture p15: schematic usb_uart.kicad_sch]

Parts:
C65, C68: 4.7u; C_0402_1005Metric_Pad0.74x0.62mm_HandSolder
C66, C67, C69: 47u; C_1206_3216Metric_Pad1.33x1.80mm_HandSolder
D3: SP0502BAHT; SOT-23
D4: D_Schottky; D_SOD-323_HandSoldering
J2: USB_C_Receptacle_USB2.0; USB_C_Receptacle_Palconn_UTC16-G
J3: USB_A; USB_A_Molex_67643_Horizontal
R21, R22: 5.1k; R_0402_1005Metric_Pad0.72x0.64mm_HandSolder
R25: 10k; R_0402_1005Metric_Pad0.72x0.64mm_HandSolder
TP1, TP6: TestPoint; TestPoint_THTPad_D1.0mm_Drill0.5mm
U4: CP2102N-Axx-xQFN28; QFN-28-1EP_5x5mm_P0.5mm_EP3.35x3.35mm

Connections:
+5VP: C66.1, C67.1, C68.1, C69.1, D4.2 (A), J2.A4 (VBUS), J2.A9 (VBUS), J2.B4 (VBUS), J2.B9 (VBUS), U4.7 (VREGIN), U4.8 (VBUS); also elsewhere on the board
/USB-UART/UART_D+: D3.2 (K), J2.A6 (D+), J2.B6 (D+), U4.4 (D+)
/USB-UART/UART_D-: D3.1 (K), J2.A7 (D-), J2.B7 (D-), U4.5 (D-)
D+: J3.3 (D+); also elsewhere on the board
D-: J3.2 (D-); also elsewhere on the board
GND: C65.2, C66.2, C67.2, C68.2, C69.2, D3.3 (A), J2.A1 (GND), J2.A12 (GND), J2.B1 (GND), J2.B12 (GND), J2.S1 (SHIELD), J3.4 (GND), J3.5 (Shield), R21.1, R22.1, U4.3 (GND), U4.29 (GND); also elsewhere on the board
unnamed: C65.1, D4.1 (K), J3.1 (VBUS)
unnamed: J2.A5 (CC1), R21.2
unnamed: J2.B5 (CC2), R22.2
unnamed: R25.1, U4.6 (VDD)
unnamed: R25.2, U4.9 (~RST)
RXConvIn: TP6.1, U4.25 (RXD); also elsewhere on the board
TXConvOut: TP1.1, U4.26 (TXD); also elsewhere on the board

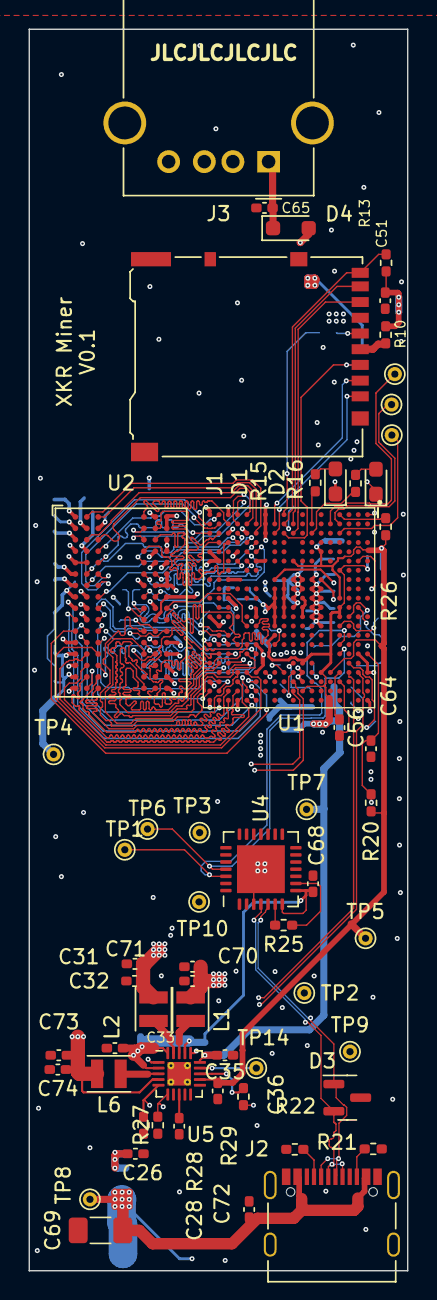
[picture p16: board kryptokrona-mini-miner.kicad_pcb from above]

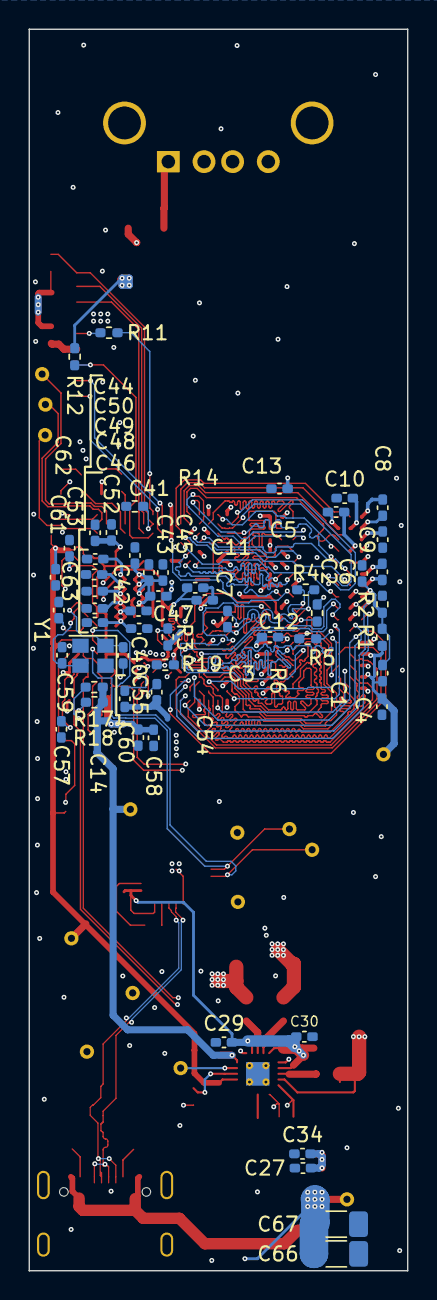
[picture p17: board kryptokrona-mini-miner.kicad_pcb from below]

Board: 4 copper layers, 26.5 x 86.9 mm, 113 parts (55 on the bottom side), 111 nets.

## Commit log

2024-04-13 Upload of untested hardware
    [Inductor_2520.step, MicroSD_DM3AT.step, SoC_H616.step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]
2024-04-18 added testpoint for TX/RX and updated readme
    [dram.kicad_sch, io1.kicad_sch, io2.kicad_sch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]
2024-04-20 Added guide and patches
    [kryptokrona-mini-miner.kicad_pcb, kryptokrona-mini-miner.step]
